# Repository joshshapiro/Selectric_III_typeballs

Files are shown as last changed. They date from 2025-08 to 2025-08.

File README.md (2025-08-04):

## 3D Printable Selectric-III 96-Character Typeface Elements

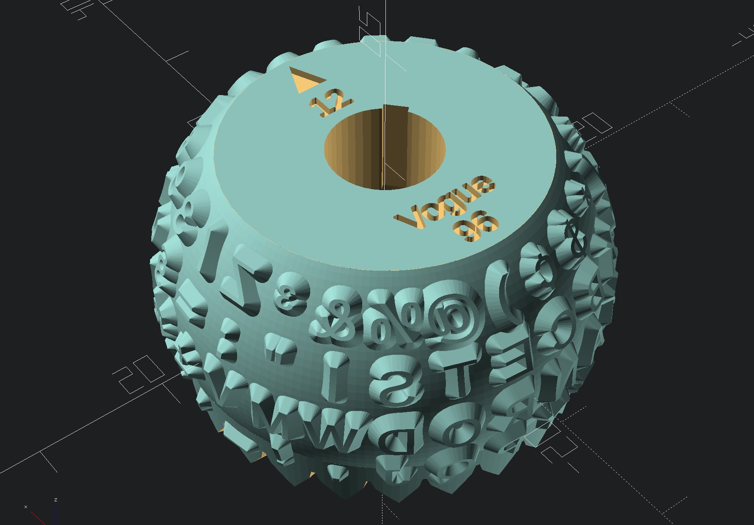
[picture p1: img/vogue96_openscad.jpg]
A CAD model for an IBM Selectric III Vogue-96 Typeface Element.


# August 3 2025: Leveraging LLMs to Support 96-Character Selectric III Typeface Elements

I'm using an AI model to rewrite the latest OpenSCAD CAD model from [Dave Hayden](https://selectricrescue.org/) to support 96-character Selectric-III typeface elements. I've added the OpenSCAD file for Vogue-96, *Selectric_III_Element96.scad*. I don't have a resin printer, so I haven't been able to do any testing, but the variables for row positions, and tilt, etc. are all configurable to achieve proper alignment. What I'm saying here, is that it's unlikely this code will work perfectly out of the box, and adjustements will need to be made regardless, based on your printer and resin.

Underside modified with additional key-notches for Selectric-III.

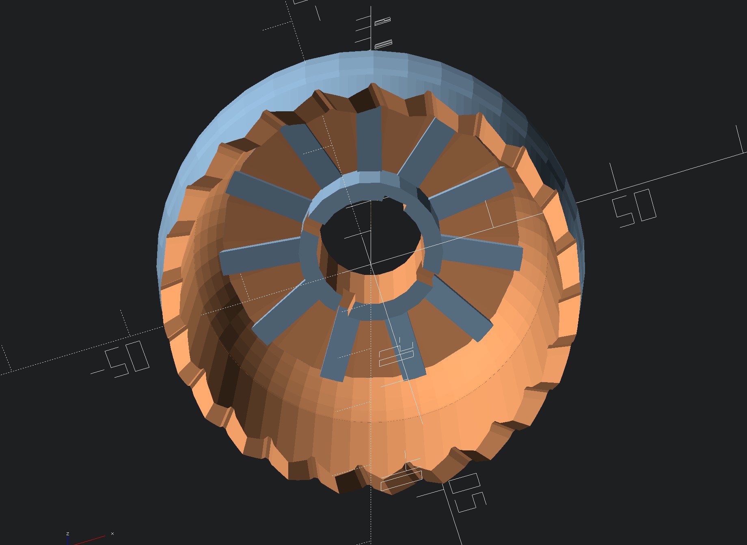
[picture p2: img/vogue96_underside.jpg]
Underside modified with additional key-notches for Selectric-III.


Feel free to take a look at and tinker the OpenSCAD file. I've tried to comment as much as possible. I've added the [Ball Clips designed by Dave Hayden](https://www.printables.com/model/416841-selectric-ball-clip/files) to the repo, distributed under [Creative Commons (4.0 International License)](https://creativecommons.org/licenses/by/4.0/) for sake of everything being in a single place.

Thanks to [Dave Hayden at Austin Selectric Rescue](https://selectricrescue.org/), [Sam Ettinger for the OG GitHub repo](https://github.com/settinger/selectric_typeballs), [1944GPW on Thingiverse](https://www.thingiverse.com/thing:4126040),  and all others who have contributed to this project!

The original README continues below.

-----------------------------------------

The [IBM Selectric typewriter](https://www.ibm.com/ibm/history/ibm100/us/en/icons/selectric/) uses an instantly-recognizable "ball" of type instead of a fanned-out array of arms like a conventional typewriter. These typeballs could be swapped out, meaning you could easily write documents with different fonts, font sizes, special characters, or different writing systems altogether.

IBM and some other vendors made lots of different typeballs, but most of them are 40-50 years old and no one has been making new typeballs for a long time. 3D printing is a natural fit for making new typeballs, but most printers still don't have the ability to produce the sharp details necessary on a sufficiently-resilient material. So it's understandable that no one made a really functional 3D-printable typeball. Until now, that is!

## Warning
Please keep in mind that the spindle that the typeball sits on is fragile. Do not force a typeball onto the spindle if it does not fit, and do not attempt to salvage a print by shaving it down. The typeball can become stuck on the delicate spindle, damaging your vintage typewriter. Similarly, do not use a typeball if it is too loose and cannot be attached securely. It could fly off and damage its surroundings.

You may wish to use a small amount of sewing machine oil on the inside of your print, to help it as it spins, and to catch any resin dust that is created by the printed ball rubbing against the spindle mount.

Any damage incurred through the use of this software and its resulting typeballs are not our liability.

## How to use the code
Things you need before getting started:
* OpenSCAD
* A Python installation with the [pymeshlab](https://pypi.org/project/pymeshlab/) package

1. Open `oneletter.scad` and change lines 11 and 12, the ones that specify the font height (in millimeters) and the font name/style for OpenSCAD to use.
1. Open `selectric_generator.py` and change line 5, the one that says `PATH TO OPENSCAD = r"{something}"` so that it points to your installation of `openscad.com` (not `openscad.exe`! They are in the same folder probably, but the `.com` is meant to be run from command line, which is what we'll be doing.
1. If you want to change the characters on the balls, edit `glyph_tables.py`. This contains a multi-dimensional array of the characters as they are arrayed on the typeball, *not as they are laid out on the keyboard*. If you want to use a different character set than the standard Latin, you'll have to find a correspondence between the new set and your preexisting keyboard layout. Sorry this part may be extra-confusing.
1. Run `selectric_generator.py`. On my machine, each character takes between 1 and 30 seconds to generate, depending on their complexity. So 88 characters will take a while, be patient!

## Acknowledgements

The blank typeball is based on [1944GPW's typeball on Thingiverse](https://www.thingiverse.com/thing:4126040), which is released under a Creative Commons-Attribution license. I suspect that my project wouldn't exist if it weren't for this one. I had to change most of their typeball dimensions, and there are major issues with the way their characters are generated, but I sure as heck would have made those same errors myself, so I'm infinitely grateful for the people before me who documented their processes!

Another project that deserves a lot of credit is [The Sincerity Machine by Jesse England](jesseengland.net/project/sincerity-machine-the-comic-sans-typewriter/). Jesse is a delight and a constant source of creative inspiration for me, and it brings me great joy to watch this project evolve with him.

## EXPLAINING HOW THE GEOMETRY WORKS, BECAUSE I'M REALLY QUITE PROUD OF IT (BUT YOU CAN SKIP THIS SECTION, IT WON'T HURT MY FEELINGS)

A Meshlab render of the octothorpe symbol with lofted edges

Getting those nice lofted edges on each glyph was not easy! I came up with a rather elaborate way that worked pretty well, but then got an excellent suggestion from Kris Slyka that works so, so much better. This is truly a community effort. I'd be very curious to hear how you would have approached it!!

The [OpenSCAD Typeball by 1944GPW](https://www.thingiverse.com/thing:4126040) attempts to loft the shapes by scaling the letterform. This was my first thought, as well, but since the letters scale around a specific point, it means the lofted sides won't all spread out evenly. Instead you get unhelpful overhangs:

An OpenSCAD render of the letter "N" with steeply slanted edges that would not print well

Instead of a scaled extrusion, we need the base to be a puffed-out offset version of the original letterform. It's not trivial to do that in an automated fashion, especially if there are small holes that will close up (like in the middle of the # character). The method I came up with uses a command-line script to extrude the letter in OpenSCAD and then displace one layer of vertices by their normal vectors. This means the vertex will always be pushed *out* away from the body of the STL.




If you look at the underside of each letter, you'll see a that this method leaves a lot of topological scars from attempts to re-mesh this self-intersecting shape. But it turned out to be pretty printable, so I released the project with this approach.



After seeing the discussion about typeballs on Mastodon, Kris Slyka approached me to suggest using OpenSCAD's `minkowski()` function. It has a reputation for being agonizingly slow, and trying to generate all the glyphs at once would exhaust my PC's memory, but with the batch-script, one-letter-at-a-time method, it can work! I highly recommend getting a recent build of OpenSCAD nightly; the fast-csg setting makes `minkowski()` operations so, so much faster.

# Extra thoughts

To affix the typeball to the typewriter, you will need a bent wire or a small clip [such as this one from Dave Hayden](https://www.printables.com/model/416841-selectric-ball-clip). Thank you Dave for encouraging me to pick up the Selectric project again!

I had been testing on a not-fully-functional Selectric I, which I think was set to 12 characters per inch. Knowing characters per inch is important for joined/cursive scripts like Mongolian. It would really help if I knew how to change the writing direction, I know some Selectrics had an RTL/LTR switch...

Other right-to-left scripts to try: Thaana, N'ko

Other typeballs to try: Osage, Tifinagh, various runes, emoji, Avoiuli, um......what else?

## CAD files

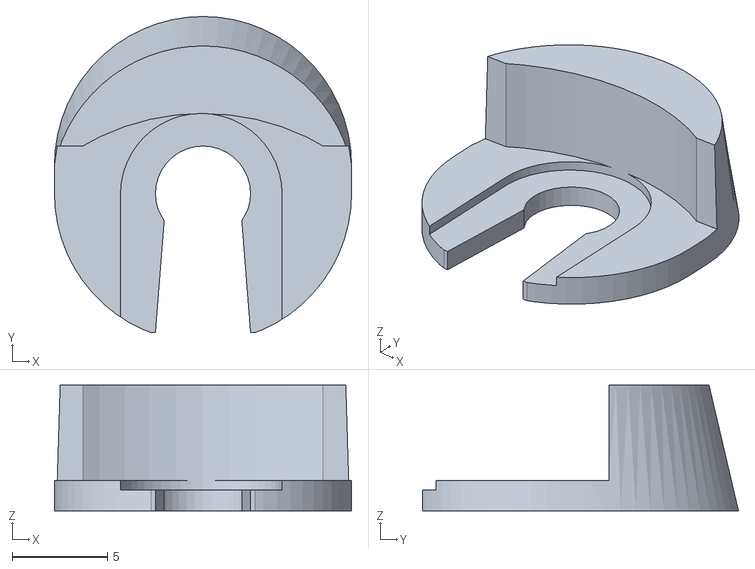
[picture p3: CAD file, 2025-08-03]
3D Models/Ball Clips/tall ball clip.stl
15.6 x 16.6 x 6.60

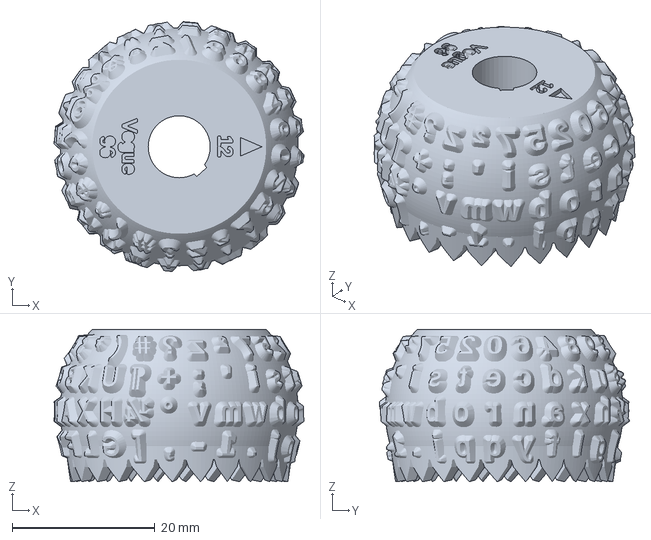
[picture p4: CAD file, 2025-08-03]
3D Models/Typeface Elements/Selectric_III_Element96.3mf
35.1 x 35.0 x 21.4 mm

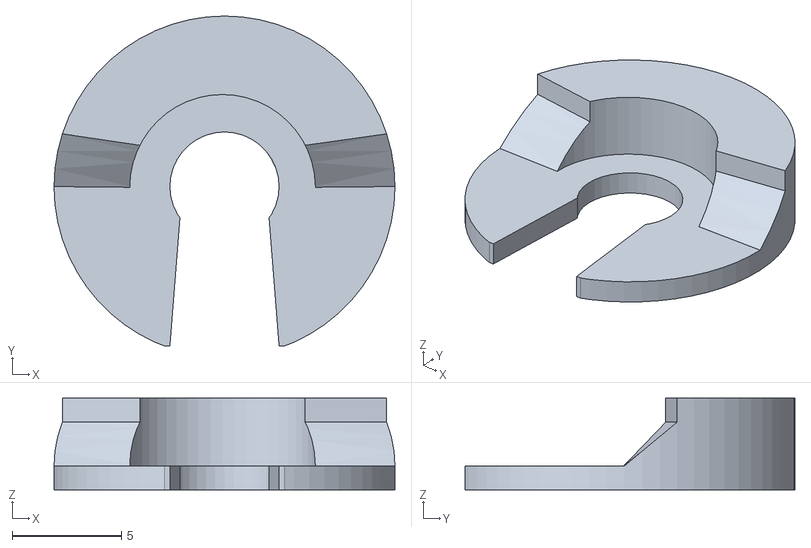
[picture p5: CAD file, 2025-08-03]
3D Models/Ball Clips/ball clip.stl
15.6 x 15.1 x 4.20

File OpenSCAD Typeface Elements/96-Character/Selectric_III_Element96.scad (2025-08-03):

// ---------- Selectric III (96-character) Typeball ----------

// -------------------
// Configuration
// -------------------

// Set to false for full character rendering (true = preview without letters)
PREVIEW_LABEL = false;

// The font name, as installed on your system
TYPEBALL_FONT = "Vogue";

// The font height (multiplied by faceScale=2.25 in LetterText)
LETTER_HEIGHT = 2.75;

// 96-character support (24 chars per row × 4 rows)
CHARACTERS_PER_LATITUDE = 24;
CHARACTER_LONGITUDE      = 360 / CHARACTERS_PER_LATITUDE;

// Nudge the whole charset around the ball (degrees).
// Use positive to rotate clockwise, negative for counter-clockwise.
CHAR_LAYOUT_ROTATION_OFFSET = 10;

// -------------------
// Character Set (exactly 96 entries, no trailing comma)
// -------------------

FULL_CHARSET = [
  // Row 1 (slots 1–24)
  "6","4","8","9","3","/","Z","³","&","%","@",")","¢","$","*","(","#","?","z","²","7","5","2","0",
  // Row 2 (25–48)
  "c","d","k","u","§","=",":","\"","I","S","T","E","C","B","K","U","¶","+",";","'","i","s","t","e",
  // Row 3 (49–72)
  "n","a","x","h","½","±","V","M","W","D","O","R","N","A","X","H","¼","°","v","m","w","b","o","r",
  // Row 4 (73–96)
  "y","f","l","g","]",",","_","!",".","J","Q","P","Y","F","L","G","[",",","-","1",".","j","p","q"
];

// -------------------
// Visual Tweaks
// -------------------

// Uniform stroke thickness tweak: applies a 2D offset to the entire glyph before 
// extrusion, making all strokes uniformly fatter (positive) or thinner (negative).
CHARACTER_WEIGHT_ADJUSTMENT = 0;

// Balance “smear” correction: inject a tiny horizontal offset before Minkowski/extrude
// so that, once the slug is curved and offset, the perceived stroke weight is even
// horizontally and vertically on the spherical surface.
HORIZONTAL_WEIGHT_ADJUSTMENT = 0.2;

// If letters with low descenders (g, j, p, q, y) extend into the detent-teeth area,
// trim those parts off so they don’t collide or leave artifacts.
TRIM_DESCENDERS             = true;

// -------------------
// Ball Geometry (tweak only for different hardware)
// -------------------

// How far each character slug sticks out from the spherical surface.
// Increase to make letters more pronounced; decrease to recess them.
LETTER_ALTITUDE           = 1.8;

// Fine-tune the tilt of each of the four rows of characters.
// This compensates for descenders (g, j, p, etc.) and balances visual weight.
//   ROW_TILT_ADJUST[0] → top row, [1] → second row, etc.
ROW_TILT_ADJUST           = [0, 0.5, 1, 2];

// Diameter of the virtual platen used to curve each slug’s face to match the typewriter platen.
// Larger values yield a flatter face; smaller values a more pronounced curve.
PLATEN_DIA                = 45;

// Preview (“Fast Render”) mesh resolution: lower → faster, rougher.
// Good for positioning and quick checks.
PREVIEW_FACETS            = 22;

// Final (“Full Render”) mesh resolution: higher → slower, smoother.
// Use for your final export or STL.
RENDER_FACETS             = 44;

// Choose the mesh resolution based on whether OpenSCAD’s $preview is active.
FACETS                    = $preview ? PREVIEW_FACETS : RENDER_FACETS;
FONT_FACETS               = FACETS;  // same resolution for extruded text curves
$fn                       = FACETS;  // global facet override for spheres/cylinders

// Angle (in degrees) between each of the four character rows.
// Controls vertical spacing around the ball.
TILT_ANGLE                = 16.2;

// Nudge every row up/down in latitude (positive = toward the flat top)
ROW_VERTICAL_OFFSET = -.5;  // try 3 or –3 to shift all rows

// Small adjustment applied only to the top row to correct any slight misalignment.
TOP_ROW_ADJUSTMENT        = -0.3;

// Enable or disable the full-length slot opposite the DEL triangle.
// Some Selectric models omit this; toggle if your tilt ring doesn’t use it.
SLOT                      = true;

// Outer radius of the typeball (half of the 33.4 mm diameter).
// Changing this will scale the entire ball.
TYPEBALL_RAD              = 33.4/2;

// Radius of the hollow interior where the reinforcement ribs attach.
// Thinner shells can reduce material but may weaken the ball.
INSIDE_RAD                = 28.15/2;

// Vertical offset (below the top) where the inner spherical pocket begins.
// Adjusting this changes the shell thickness at the top.
INSIDE_CURVE_START        = 2;

// Total height of the typeball including skirt, from flat top to skirt bottom.
TYPEBALL_HEIGHT           = 21.5;

// Height of the flat top surface above the sphere’s center.
// This defines how deep the boss and DEL triangle sit.
TYPEBALL_TOP_ABOVE_CENTRE = 11.4;

// Thickness of that flat top plate before the ribs begin.
TYPEBALL_TOP_THICKNESS    = 1.65;

// Distance from the sphere center to the base of the DEL triangle marker.
DEL_BASE_FROM_CENTRE      = 8.2;

// Depth of the DEL triangle cut into the flat top.
DEL_DEPTH                 = 0.6;

// Upper radius of the detent-teeth skirt (where teeth start).
TYPEBALL_SKIRT_TOP_RAD    = 31.9/2;

// Lower radius of the detent-teeth skirt (where teeth end).
TYPEBALL_SKIRT_BOTTOM_RAD = 30.5/2;

// Z-offset of the skirt’s top edge relative to the sphere center.
// Defines vertical placement of the teeth.
TYPEBALL_SKIRT_TOP_BELOW_CENTRE = -sqrt(
  TYPEBALL_RAD*TYPEBALL_RAD
  - TYPEBALL_SKIRT_TOP_RAD*TYPEBALL_SKIRT_TOP_RAD
);

// Vertical height of the detent-teeth skirt (depth of the teeth ring).
SKIRT_HEIGHT              = TYPEBALL_HEIGHT
                             - TYPEBALL_TOP_ABOVE_CENTRE
                             + TYPEBALL_SKIRT_TOP_BELOW_CENTRE;

// Radial offset of each detent-tooth peak from the sphere center.
// Controls how “tall” each tooth sits.
TOOTH_PEAK_OFFSET_FROM_CENTRE = 6.1;

// Inner and outer radii of the boss that fits into the tilt ring.
// These must match the typewriter’s tilt-ring socket dimensions.
BOSS_INNER_RAD            = 4.35;
BOSS_OUTER_RAD            = 5.8;

// Height of the boss (depth of the tilt-ring socket).
BOSS_HEIGHT               = 8.07;

// Rotation (degrees) of the small partial notch in the boss (mechanical key).
NOTCH_ANGLE               = 131.8;
// Width, depth, and height of that notch.
NOTCH_WIDTH               = 1.1;
NOTCH_DEPTH               = 2;
NOTCH_HEIGHT              = 2.2;

// Rotation (degrees) of the full-length slot opposite the notch.
SLOT_ANGLE                = NOTCH_ANGLE + 180;
// Width and depth of that slot.
SLOT_WIDTH                = 1.9;
SLOT_DEPTH                = 0.4;

// Number of internal reinforcement ribs under the top face.
// More ribs = stronger but heavier.
RIBS                      = 11;
// Physical dimensions of each rib (length from boss, thickness, height).
RIB_LENGTH                = 8;
RIB_WIDTH                 = 2;
RIB_HEIGHT                = 2.5;

// Tiny offset to prevent z-fighting where faces intersect.
EPSILON                   = 0.001;


// -------------------
// Modules
// -------------------

module Labels() {
  offset(r=0.12) {
    translate([-0.1,14,0])
      text("12", size=2, font=TYPEBALL_FONT, halign="center");
    translate([0,0.6,0])
      text(TYPEBALL_FONT, size=2, font=TYPEBALL_FONT, halign="center");
    translate([0,-2.5,0])                // shift down below the font name
      text("96", size=2, font=TYPEBALL_FONT, halign="center");
  }
}


module SelectricLayout96() {
  for (l = [0 : 3]) {
    // base row angle + per-row tweak + global vertical offset
    tiltAngle = (2 - l) * TILT_ANGLE
               + (l == 0 ? TOP_ROW_ADJUSTMENT : 0)
               + ROW_VERTICAL_OFFSET;

    for (p = [0 : CHARACTERS_PER_LATITUDE - 1]) {
      idx  = CHARACTERS_PER_LATITUDE * l + p;
      char = FULL_CHARSET[idx];
      if (char != "") {
        // place each slug clockwise plus any rotation offset
        lon = p * CHARACTER_LONGITUDE + CHAR_LAYOUT_ROTATION_OFFSET;
        GlobalPosition(TYPEBALL_RAD, tiltAngle, lon, ROW_TILT_ADJUST[l])
          LetterText(LETTER_HEIGHT, LETTER_ALTITUDE, TYPEBALL_FONT, char);
      }
    }
  }
}



module TypeBall() {
  if (is_undef(PREVIEW_LABEL) || !PREVIEW_LABEL) {
    difference() {
      SelectricLayout96();
      TrimTop();
      if (TRIM_DESCENDERS)
        translate([
          0,0,
          TYPEBALL_SKIRT_TOP_BELOW_CENTRE - SKIRT_HEIGHT - EPSILON
        ])
          DetentTeeth();
    }
  }
  difference() {
    HollowBall();
    if (SLOT) Slot();
    Notch();
    Del();
    FontName();
  }
}

module GlobalPosition(r, latitude, longitude, rotAdjust) {
  x = r * cos(latitude);
  y = 0;
  z = r * sin(latitude);
  rotate([0,0,longitude])
    translate([x,y,z])
      rotate([0, 90 - latitude - rotAdjust, 0])
        children();
}
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

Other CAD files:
3D Models/Ball Clips/ball clip.skp
3D Models/Ball Clips/tall ball clip.skp
3D Models/Typeface Elements/Selectric_III_Element96.stl

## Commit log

2025-08-03 Cleaned up repo of old files, added 96-char element file
    [Selectric_III_Element96_v001.scad, oneletter.scad, typeball_blank.STL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]
2025-08-03 Added ball clips
    [ball clip.skp, ball clip.stl, tall ball clip.skp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]
2025-08-03 Added additional key-notches to underside to support Selectric-III, reworked file naming
    [Selectric_III_Element96.scad]
2025-08-03 Updated splash pic, enabled full render mode in file
    [Selectric_III_Element96_v001.scad]
2025-08-03 Added 3D models, updated splash image
    [Selectric_III_Element96.3mf, Selectric_III_Element96.stl, ball clip.skp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]
2025-08-04 Moved 3mf model file to correct folder, removed duplicate .scad file.
    [Selectric_III_Element96.3mf, Selectric_III_Element96_v001.scad]
2025-08-04 Disable preview mode, changed typeface label size to 12
    [Selectric_III_Element96.scad]
